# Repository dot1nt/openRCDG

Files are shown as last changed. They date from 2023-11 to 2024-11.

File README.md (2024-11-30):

# openRCDG
An Arduino based rc drift gyro.

## Building
The easiest way to build and upload this project is to use the [platformio vscode extension](https://platformio.org/install/ide?install=vscode).

If you are building for a board other than the arduino micro, you will need to change/add the board in the platformio.ini file.

## Configuration
Configuration variables can be found in the config.h file.

## Hardware
I only tested this on an Arduino micro and nano, but it should work on most other boards as well.

Example schematic for an Arduino pro micro with GY-521 imu:

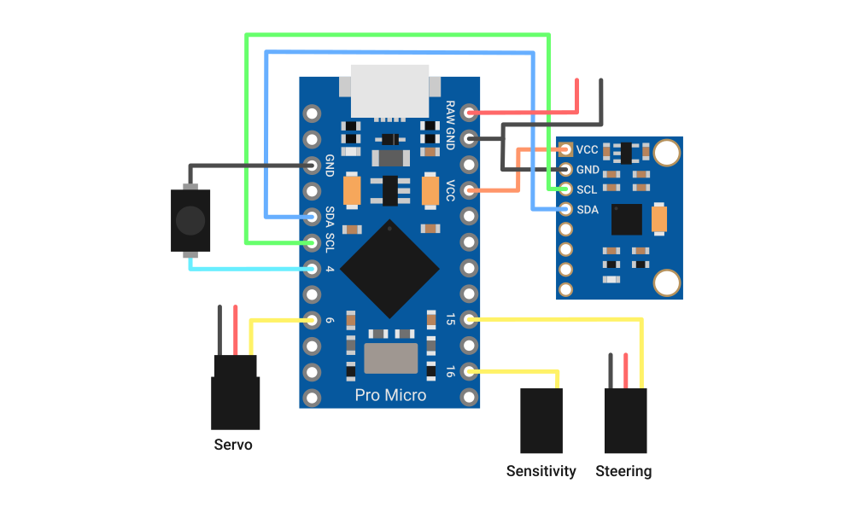
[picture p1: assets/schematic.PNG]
schematic


## PCB
Files for the pcb and case can be found in the pcb/case folders. The board works, but component placement/routing isn't optimal. The pcb uses components from a **3.3V** arduino pro micro and mpu6050 board. 3D printing the case works fine. 

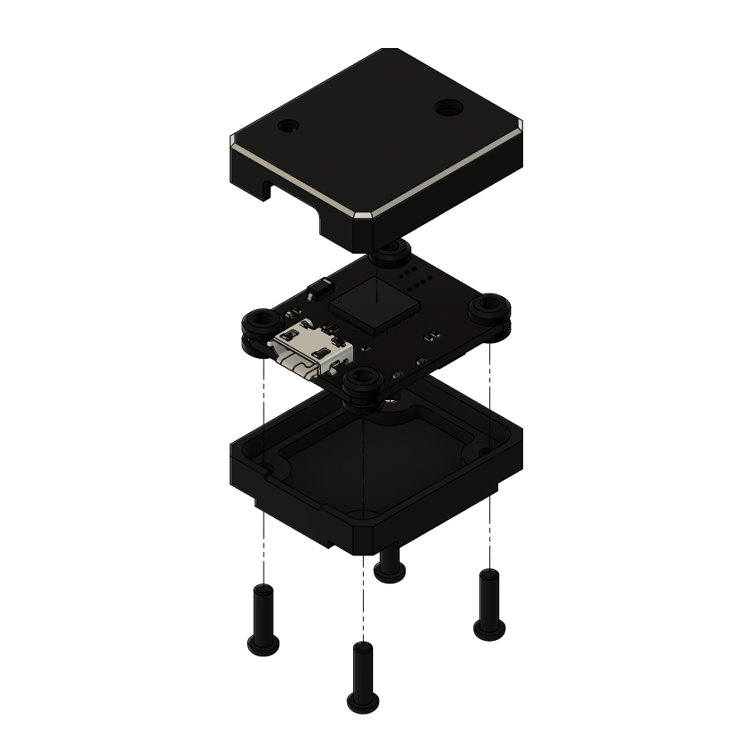
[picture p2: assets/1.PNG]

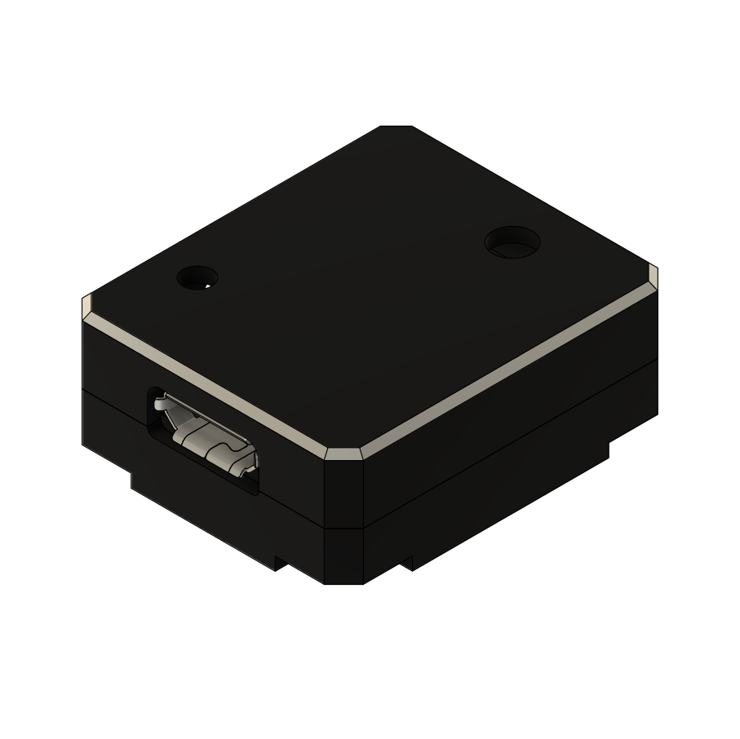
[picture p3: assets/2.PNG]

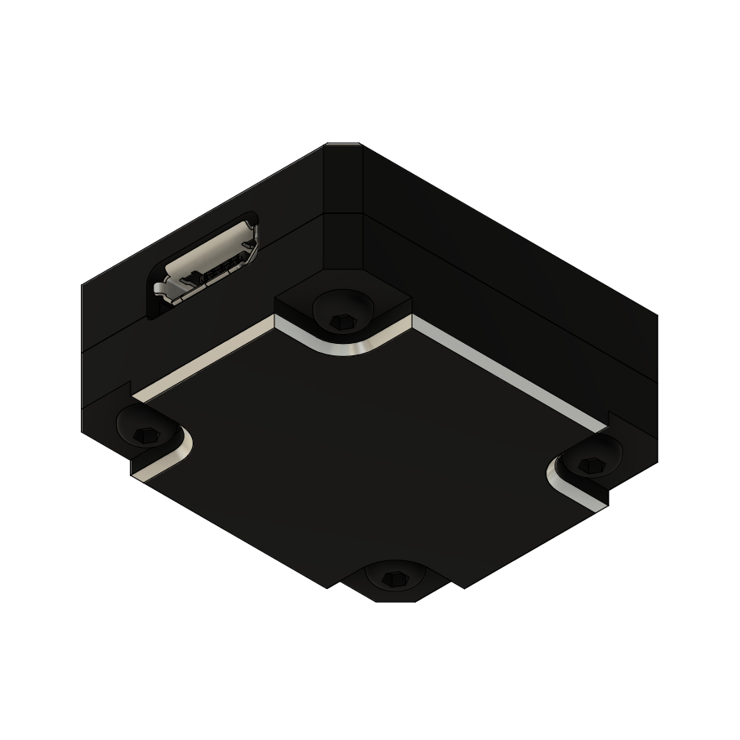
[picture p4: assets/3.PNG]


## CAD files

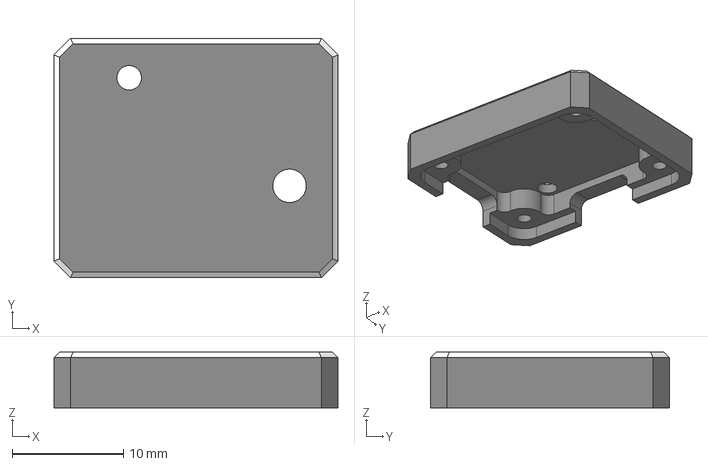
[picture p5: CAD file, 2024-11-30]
case/Top.step
25.5 x 21.5 x 5.00 mm

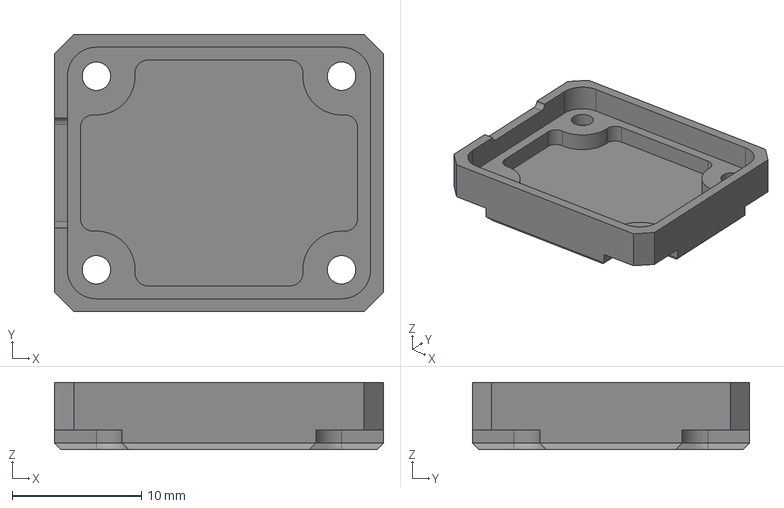
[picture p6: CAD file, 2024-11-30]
case/Bottom.step
25.5 x 21.5 x 5.20 mm

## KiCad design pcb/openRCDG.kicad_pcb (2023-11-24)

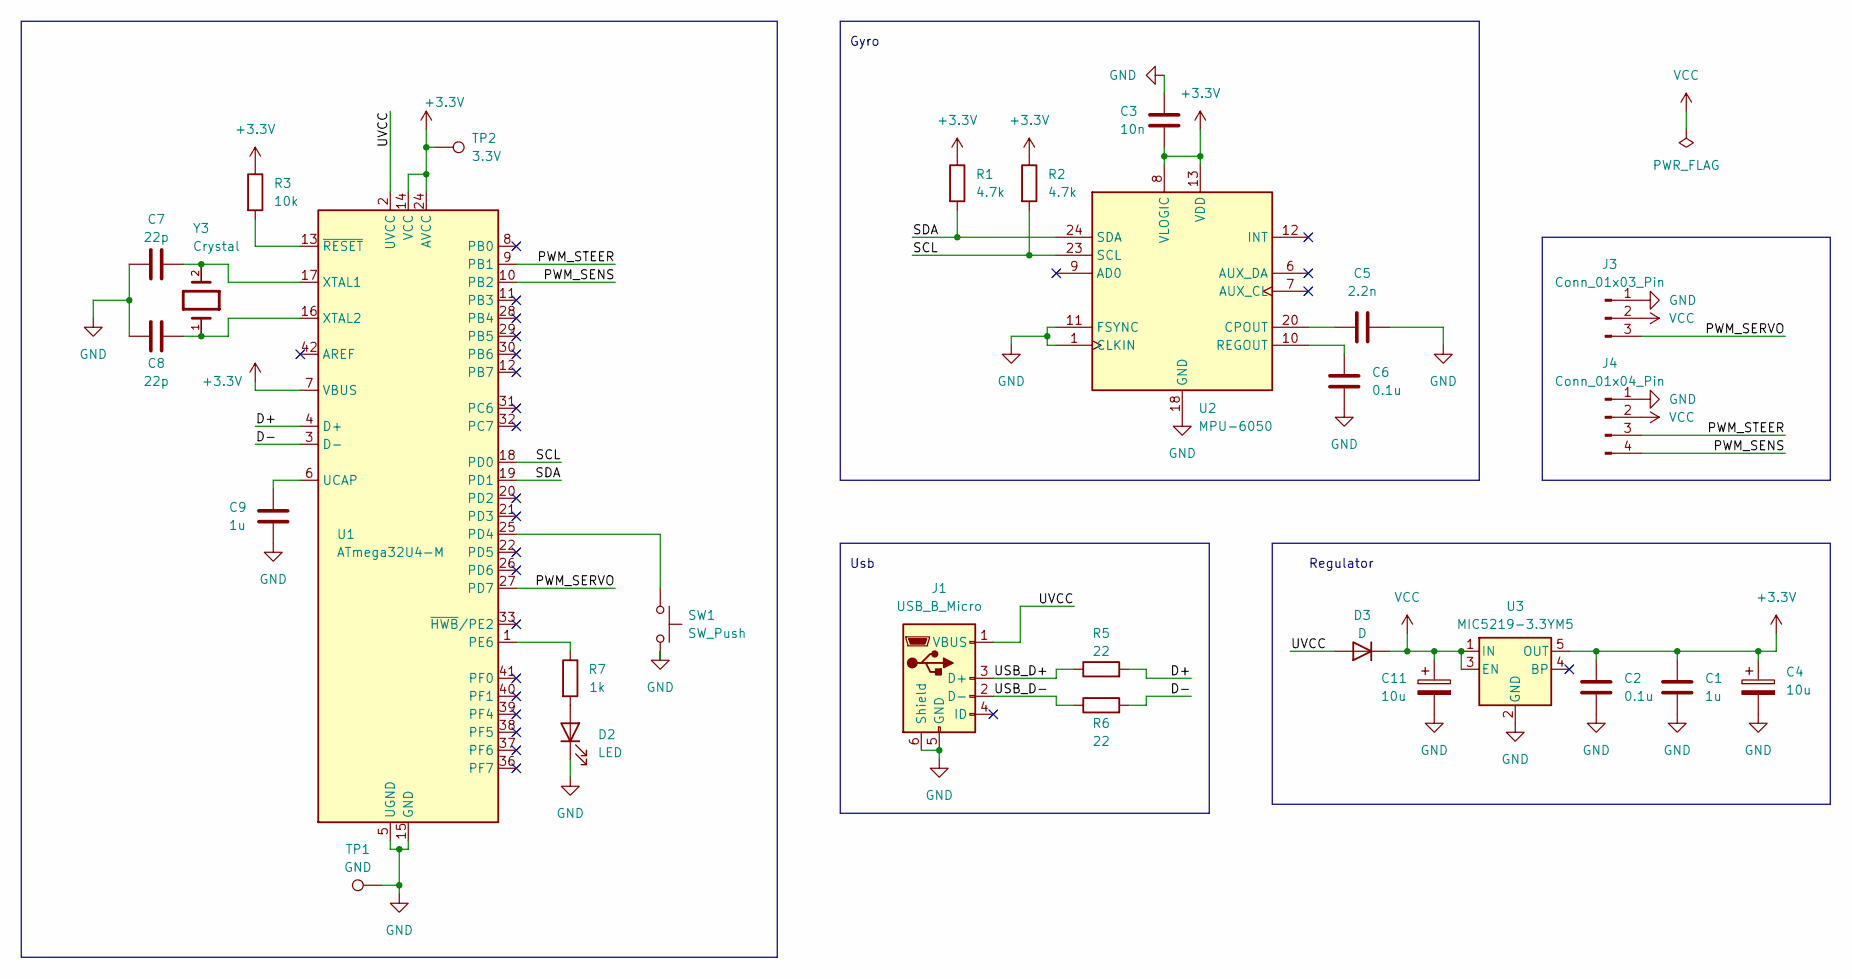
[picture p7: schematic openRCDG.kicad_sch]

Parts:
C1, C9: 1u; C_0402_1005Metric_Pad0.74x0.62mm_HandSolder
C2, C6: 0.1u; C_0402_1005Metric_Pad0.74x0.62mm_HandSolder
C3: 10n; C_0402_1005Metric_Pad0.74x0.62mm_HandSolder
C4, C11: 10u; CP_EIA-3216-18_Kemet-A_Pad1.58x1.35mm_HandSolder
C5: 2.2n; C_0402_1005Metric_Pad0.74x0.62mm_HandSolder
C7, C8: 22p; C_0402_1005Metric_Pad0.74x0.62mm_HandSolder
D2: LED; LED_0402_1005Metric_Pad0.77x0.64mm_HandSolder
D3: D; D_SOD-123
J1: USB_B_Micro; USB_Micro-B_Amphenol_10118194_Horizontal
J3: Conn_01x03_Pin; PinHeader_1x03_P1.00mm_Vertical
J4: Conn_01x04_Pin; PinHeader_1x04_P1.00mm_Vertical
R1, R2: 4.7k; R_0402_1005Metric_Pad0.72x0.64mm_HandSolder
R3: 10k; R_0402_1005Metric_Pad0.72x0.64mm_HandSolder
R5, R6: 22; R_0402_1005Metric_Pad0.72x0.64mm_HandSolder
R7: 1k; R_0402_1005Metric_Pad0.72x0.64mm_HandSolder
SW1: SW_Push; SW_Push_1P1T_NO_Vertical_Wuerth_434133025816
TP1: GND; TestPoint_Pad_D1.5mm
TP2: 3.3V; TestPoint_Pad_D1.5mm
U1: ATmega32U4-M; QFN-44-1EP_7x7mm_P0.5mm_EP5.2x5.2mm
U2: MPU-6050; InvenSense_QFN-24_4x4mm_P0.5mm
U3: MIC5219-3.3YM5; SOT-23-5
Y3: Crystal; arduino_micro_crystal

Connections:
+3.3V: C1.1, C2.1, C3.1, C4.1, R1.1, R2.1, R3.1, TP2.1, U1.7 (VBUS), U1.14 (VCC), U1.24 (AVCC), U1.34 (VCC), U1.44 (AVCC), U2.8 (VLOGIC), U2.13 (VDD), U3.5 (OUT)
/D+: R5.2, U1.4 (D+)
/D-: R6.2, U1.3 (D-)
/PWM_SENS: J4.4, U1.10 (PB2)
/PWM_SERVO: J3.3, U1.27 (PD7)
/PWM_STEER: J4.3, U1.9 (PB1)
/SCL: R2.2, U1.18 (PD0), U2.23 (SCL)
/SDA: R1.2, U1.19 (PD1), U2.24 (SDA)
/USB_D+: J1.3 (D+), R5.1
/USB_D-: J1.2 (D-), R6.1
/UVCC: D3.2 (A), J1.1 (VBUS), U1.2 (UVCC)
GND: C1.2, C2.2, C3.2, C4.2, C5.2, C6.2, C7.1, C8.1, C9.2, C11.2, D2.1 (K), J1.5 (GND), J1.6 (Shield), J3.1, J4.1, SW1.2, TP1.1, U1.5 (UGND), U1.15 (GND), U1.23 (GND), U1.35 (GND), U1.43 (GND), U1.45 (GND), U2.1 (CLKIN), U2.11 (FSYNC), U2.18 (GND), U3.2 (GND)
unnamed: D2.2 (A), R7.2
unnamed: SW1.1, U1.25 (PD4)
unnamed: R7.1, U1.1 (PE6)
unnamed: C9.1, U1.6 (UCAP)
unnamed: C7.2, U1.17 (XTAL1), Y3.2
unnamed: C8.2, U1.16 (XTAL2), Y3.1
unnamed: R3.2, U1.13 (~RESET)
unnamed: C5.1, U2.20 (CPOUT)
unnamed: C6.1, U2.10 (REGOUT)
VCC: C11.1, D3.1 (K), J3.2, J4.2, U3.1 (IN), U3.3 (EN)

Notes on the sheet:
Regulator
Usb
Gyro

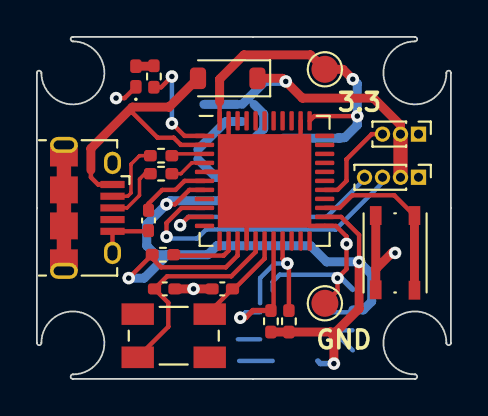
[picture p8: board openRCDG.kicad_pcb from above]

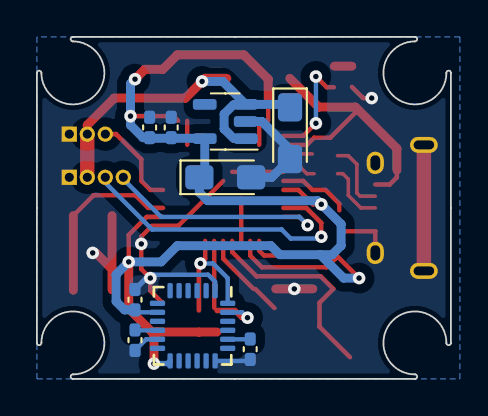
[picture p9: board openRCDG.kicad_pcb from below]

Board: 2 copper layers, 23.0 x 19.0 mm, 28 parts (9 on the bottom side), 22 nets.

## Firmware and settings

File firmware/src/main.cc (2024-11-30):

#include <Arduino.h>
#include <Servo.h>

#include "config.h"

#include "drivers/button.h"
#include "drivers/led.h"
#include "drivers/pwm.h"

#include "drivers/imu/imu.h"
#include "drivers/imu/mpu6050.h"

#include "endpoints.h"
#include "mixer.h"
#include "pid.h"

///////////////////////////////////////////////////////

constexpr float loopTime = 1 / static_cast<float>(Config::LOOP_TIME_HZ);

Endpoints endpoints(Config::DEFAULT_ENDPOINTS);

Button button(Config::BUTTON_PIN);

Led led(Config::LED_PIN);

Imu *imu;

PidController pidController(
    Config::PID_P,
    Config::PID_I,
    Config::PID_D,
    Config::PID_D_FILTER_CUTOFF,
    loopTime);

Curve gyroCurve;

Mixer mixer(gyroCurve, endpoints, Config::REVERSE);

PT1Filter gyroFilter(Config::GYRO_LPF_CUTOFF, loopTime);

PwmReader pwmSteering(Config::PWM_STEERING_PIN);
PwmReader pwmSensitivity(Config::PWM_SENSITIVITY_PIN);

Servo steeringServo;

///////////////////////////////////////////////////////

ISR(PCINT0_vect) {
  pwmSteering.update();
  pwmSensitivity.update();
}

///////////////////////////////////////////////////////

void waitForButtonPress() {
  while (true) {
    if (button.update()) {
      return;
    }

    steeringServo.writeMicroseconds(pwmSteering.getValue());
  }
}

void configureEndpoints() {
  led.low();
  delay(500);

  led.blink(1);
  waitForButtonPress();
  endpoints.setEndpointFromValue(pwmSteering.getValue());

  led.blink(2);
  waitForButtonPress();
  endpoints.setEndpointFromValue(pwmSteering.getValue());

  led.blink(3);
  waitForButtonPress();
  endpoints.setCenter(pwmSteering.getValue());

  endpoints.saveToEEPROM(0);

  led.setupFinished();
}

// delayMicroseconds() has a 16383 limit
void _delayMicroseconds(unsigned long us) {
  unsigned long delay = us;

  while (delay > 16383) {
    delay -= 16383;
    delayMicroseconds(16383);
  }

  delayMicroseconds(delay);
}

///////////////////////////////////////////////////////

void setup() {
  Serial.begin(Config::SERIAL_BAUDRATE);

  delay(1000);

  PCICR |= B00000001;  // interrupts group 0
  PCMSK0 |= B00000110; // interrupts pcint 1, 2

  steeringServo.attach(Config::PWM_SERVO_PIN);

  endpoints.getFromEEPROM(0);

  switch (Config::GYRO_CURVE_TYPE) {
  case Curve::CurveType::CUSTOM:
    gyroCurve.setCustomCurve(Config::CUSTOM_GYRO_CURVE);
    break;

  default:
    gyroCurve.setCurveType(Config::GYRO_CURVE_TYPE);
    break;
  }

  switch (Config::IMU_TYPE) {
  case Config::ImuType::MPU6050:
    imu = new Mpu6050();
    break;
  }

  led.setupFinished();
}

///////////////////////////////////////////////////////

unsigned long loopTimeUs = loopTime * 1e6;

void loop() {
  unsigned long startTime = micros();

  /////////////

  if (Config::USE_BUTTON) {
    if (button.update()) {
      configureEndpoints();
    }
  }

  float gyroOutput = imu->getGyroAxis(Config::GYRO_AXIS);

  float filteredGyroOutput = gyroFilter.update(gyroOutput);

  float pidOutput = pidController.update(filteredGyroOutput);

  unsigned long sensitivity;
  if (Config::USE_SENSITIVITY_INPUT) {
    sensitivity = pwmSensitivity.getValue();
  } else {
    sensitivity = Config::DEFAULT_SENSITIVITY;
  }

  float mixerOutput = mixer.update(
      pidOutput,
      pwmSteering.getValue(),
      sensitivity);

  steeringServo.writeMicroseconds(mixerOutput);

  /////////////

  if (micros() - startTime > loopTimeUs) {
    return;
  }

  unsigned long delay = loopTimeUs - micros() + startTime;

  _delayMicroseconds(delay);
}

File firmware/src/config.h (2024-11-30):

#pragma once

#include "curve.h"

namespace Config {

enum class ImuType {
  MPU6050,
};

// Baudrate for the serial port. Used only for debugging.
constexpr int SERIAL_BAUDRATE = 9600;

// Time in Hz every software loop should take.
constexpr int LOOP_TIME_HZ = 1000;

// Change to false if no sensitivity input is used.
constexpr bool USE_SENSITIVITY_INPUT = true;

// Sensitivity if USE_SENSITIVITY_INPUT is false. From 1000 - 2000.
constexpr unsigned long DEFAULT_SENSITIVITY = 2000;

// Pins to which the the sensitivity and steering signals are connected to.
// Must to be a PCINT pin. Currently PCINT1 and 2 are used.
// If you want to use a different pin, make sure to also change PCICR and PCMSK0 in the main.cc file.
// PCINT1 and 2 on an Arduino nano would be pin 9 and 10.
constexpr int PWM_SENSITIVITY_PIN = 16;
constexpr int PWM_STEERING_PIN = 15;

// Pin where the servo is connected.
constexpr int PWM_SERVO_PIN = 6;

// Pin where the LED is connected.
// Change this to LED_BUILDIN if you want to use the Arduino's onbaord LED.
constexpr int LED_PIN = 7;

// Pin where the button is connected.
// Change USE_BUTTON to false if no button is connected.
constexpr bool USE_BUTTON = true;
constexpr int BUTTON_PIN = 4;

// Default endpoints if USE_BUTTON is false.
float DEFAULT_ENDPOINTS[3] = {1000.0f, 1500.0f, 2000.0f};

// P, I and D for the pid controller.
// More info here: https://en.wikipedia.org/wiki/Proportional%E2%80%93integral%E2%80%93derivative_controller
constexpr float PID_P = 10.0f;
constexpr float PID_I = 0.0f;
constexpr float PID_D = -0.5f;

// Reverses the servo output.
constexpr bool REVERSE = true;

constexpr ImuType IMU_TYPE = ImuType::MPU6050;

// Gyro axis that should be used.
// 0 = X, 1 = Y, 2 = Z
constexpr int GYRO_AXIS = 2;

// LINEAR, SIN, LOG, CUSTOM
constexpr Curve::CurveType GYRO_CURVE_TYPE = Curve::LINEAR;

// Only active if GYRO_CURVE_TYPE = Curve::CUSTOM.
// This holds the corresponding y values for the x values 0.0, 0.1, 0.2 .. 0.9, 1.0.
float CUSTOM_GYRO_CURVE[11] = {0.0f, 0.25f, 0.35f, 0.53f, 0.6f, 0.66f, 0.73f, 0.8f, 0.86f, 0.93f, 1.0f};

// Gyro low pass filter cutoff in Hz.
// higher = faster, noisier response
// lower = slower, smoother response
constexpr float GYRO_LPF_CUTOFF = 10.0f;

// Pid d filter cutoff in Hz
constexpr float PID_D_FILTER_CUTOFF = 10.0f;

} // namespace Config
